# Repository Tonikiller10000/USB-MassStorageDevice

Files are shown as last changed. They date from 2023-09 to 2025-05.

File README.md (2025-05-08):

# USB MassStorageDevice

This project is an USB mass storage made with:
- 2x K9GAG08U0E 16GB NAND flash memory chips (32GB total) 
- lateral switch for read-only operation mode 
- an ST72681 memory controller 
- LD3985 3.3V regulator
- 12MHz crystal resonator
- other passive components

After testing the board with an 220nF THT ceramic capacitor because the SMD did not arrived in time, I made some improvisations trying to fix it, and
 it still `does not work`. It seems like the memory chip and the controller ic\`s are not compatible so 
 `I will have another look on this project in the distant future` with different components. I am looking into STM32 specs and usb 3.0 to SDMMC DMA transfer
 including some software functions with hardware interaction sounds verry intheresting. And cheaper.

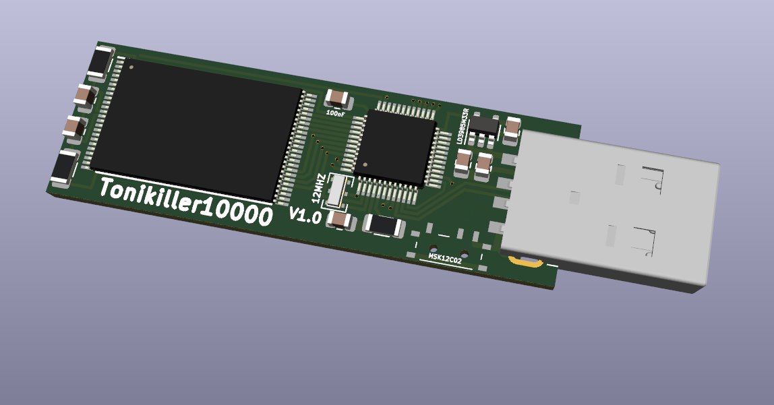
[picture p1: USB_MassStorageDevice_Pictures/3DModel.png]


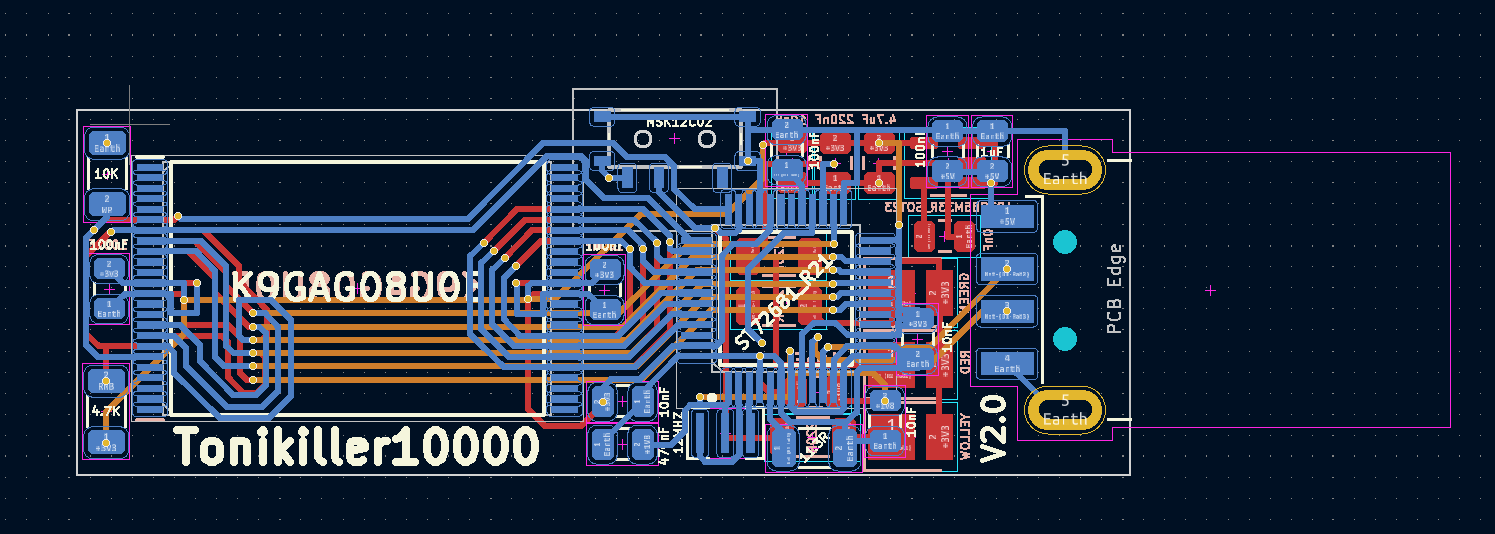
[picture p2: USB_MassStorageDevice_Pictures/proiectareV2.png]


Schematic:

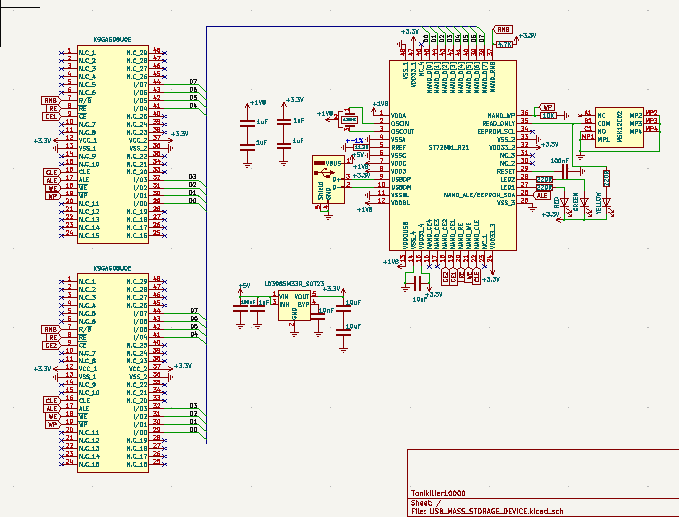
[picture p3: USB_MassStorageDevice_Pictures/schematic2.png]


<table>
  <tr>
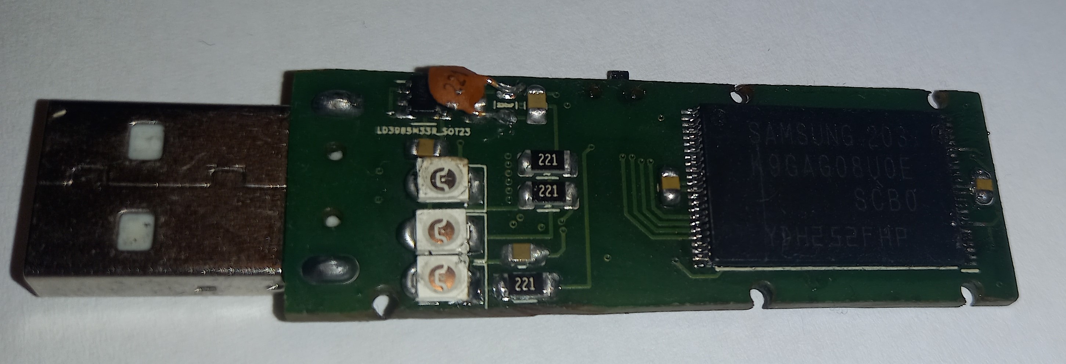
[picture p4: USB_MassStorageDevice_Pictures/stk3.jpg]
    <td></td>
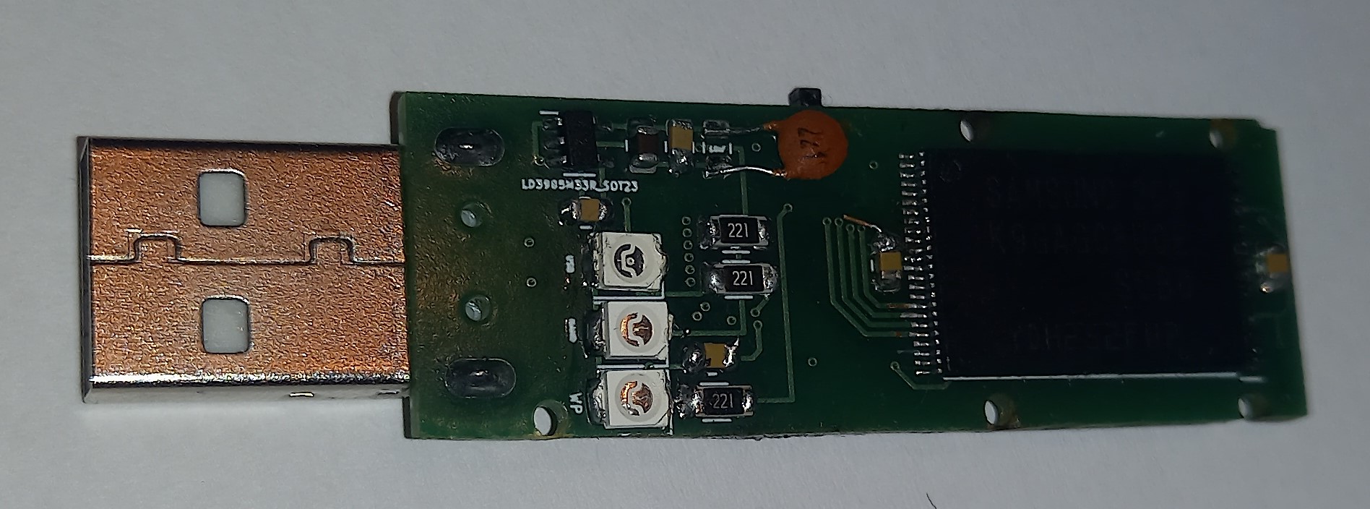
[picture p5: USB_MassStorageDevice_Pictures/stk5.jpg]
    <td></td>
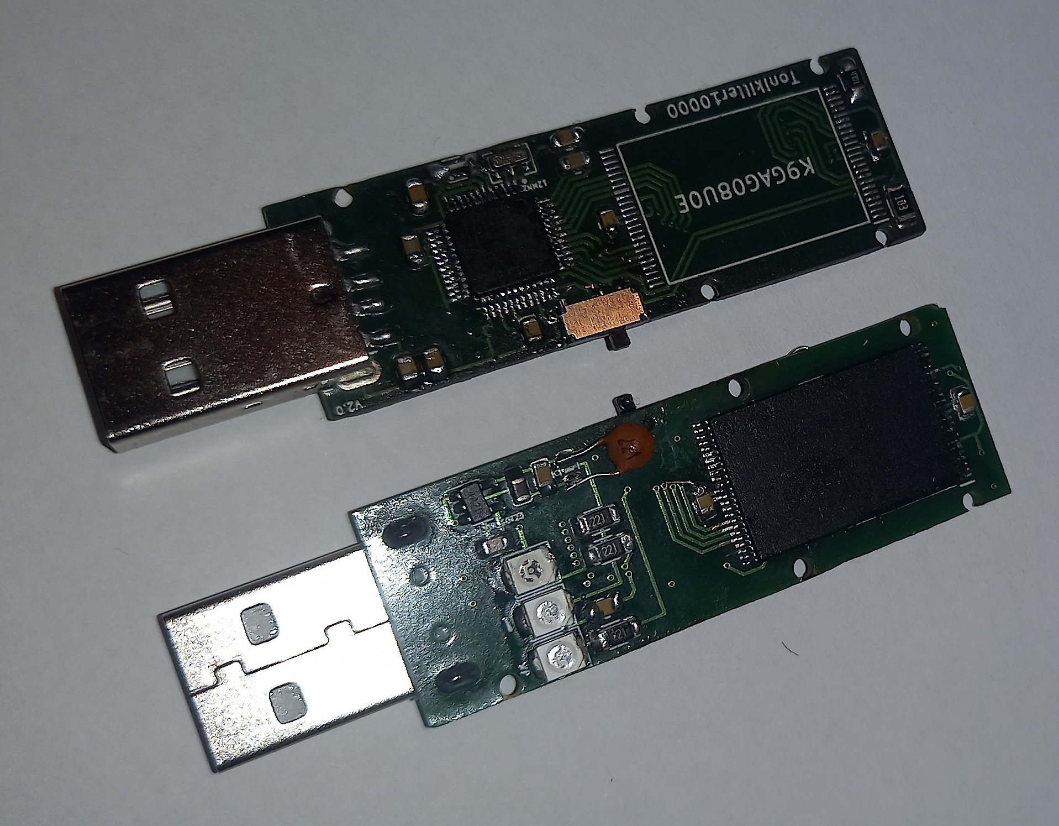
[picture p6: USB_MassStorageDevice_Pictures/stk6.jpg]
    <td></td>
  </tr>
 </table>

Datasheets:
- NAND: https://pdf1.alldatasheet.com/datasheet-pdf/view/104019/STMICROELECTRONICS/ST72681.html
- Controller: https://pdf1.alldatasheet.com/datasheet-pdf/view/1134995/SAMSUNG/K9GAG08U0E.html
- Regulator: https://pdf1.alldatasheet.com/datasheet-pdf/view/85490/STMICROELECTRONICS/LD3985.html

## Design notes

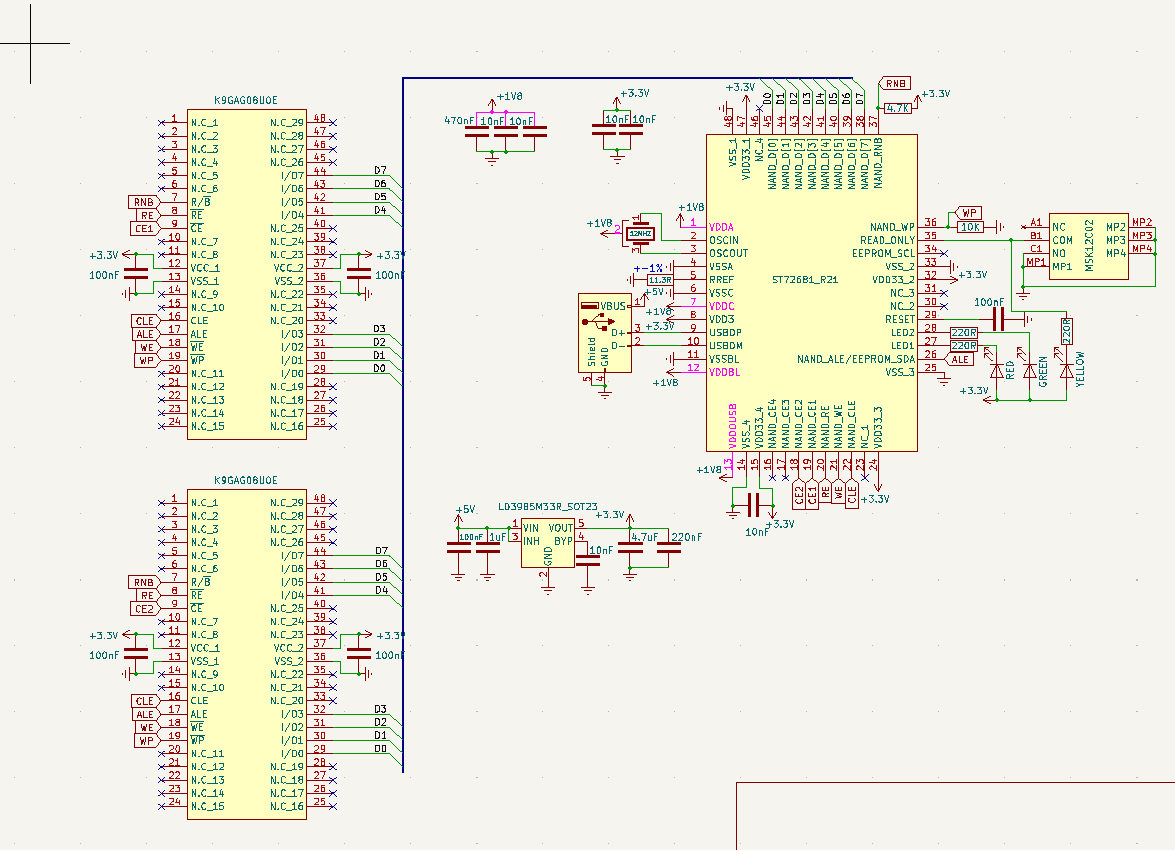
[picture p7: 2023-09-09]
USB_MassStorageDevice_Pictures/schematic.png

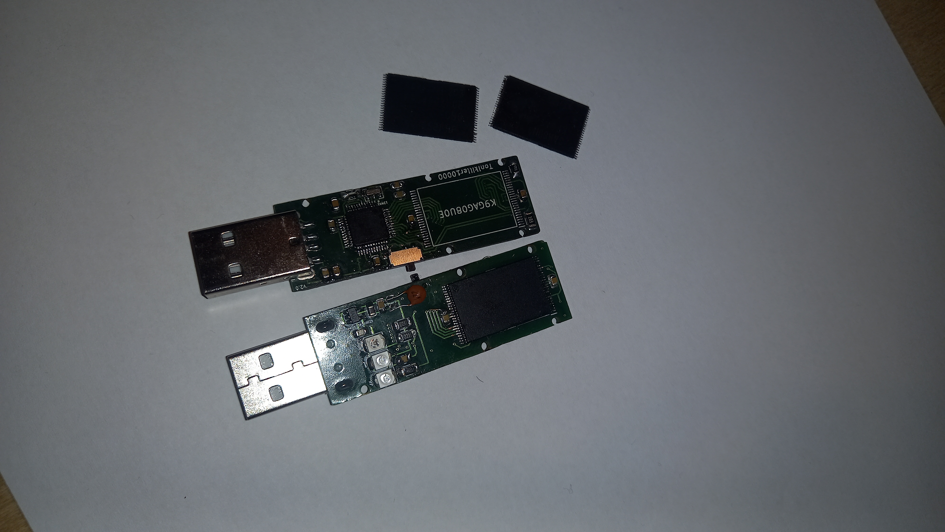
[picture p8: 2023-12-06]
USB_MassStorageDevice_Pictures/stk1.jpg

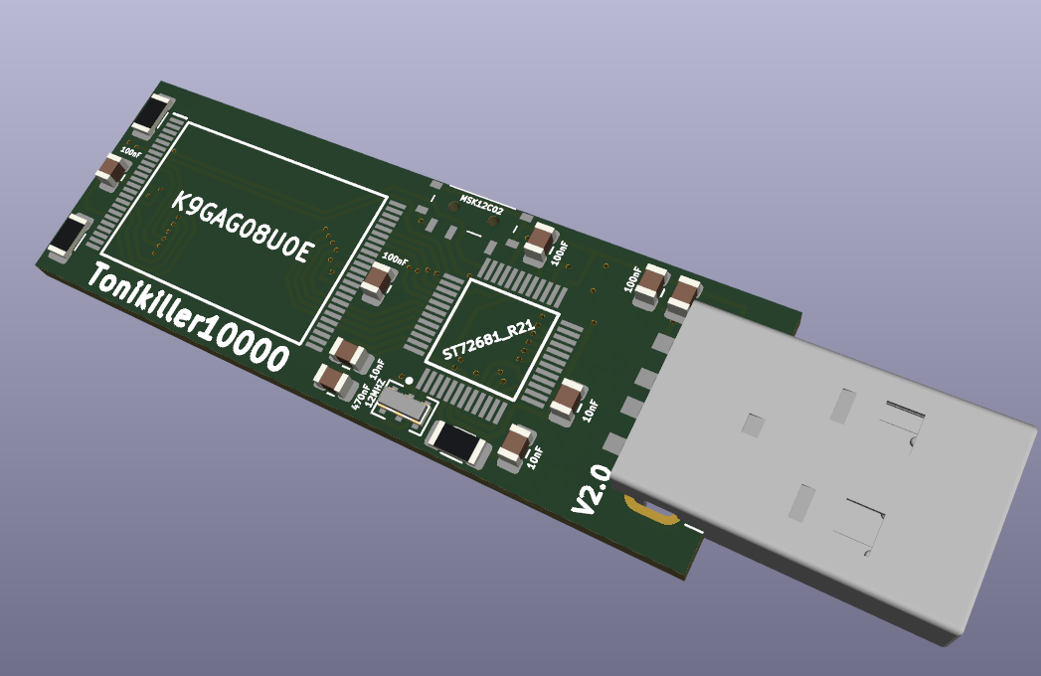
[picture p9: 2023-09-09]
USB_MassStorageDevice_Pictures/3DModel1.png

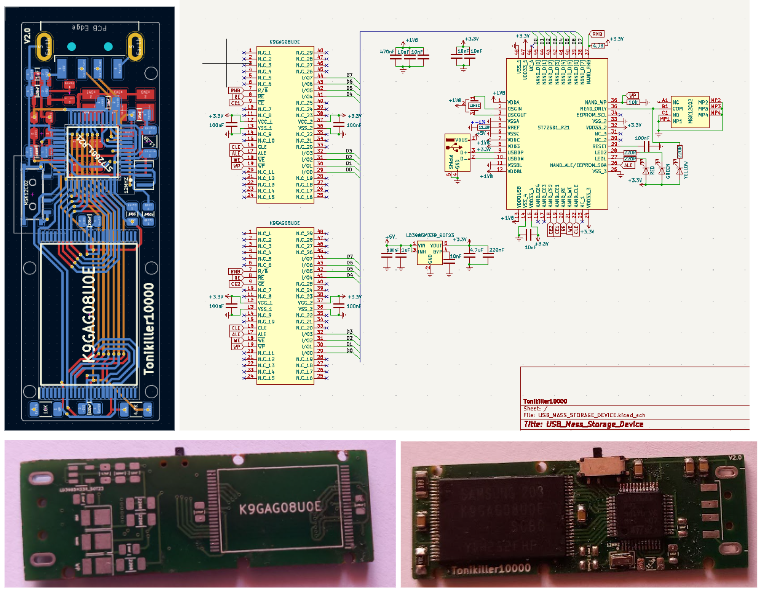
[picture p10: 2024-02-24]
USB_MassStorageDevice_Pictures/Screenshot 2023-11-07 201436.png

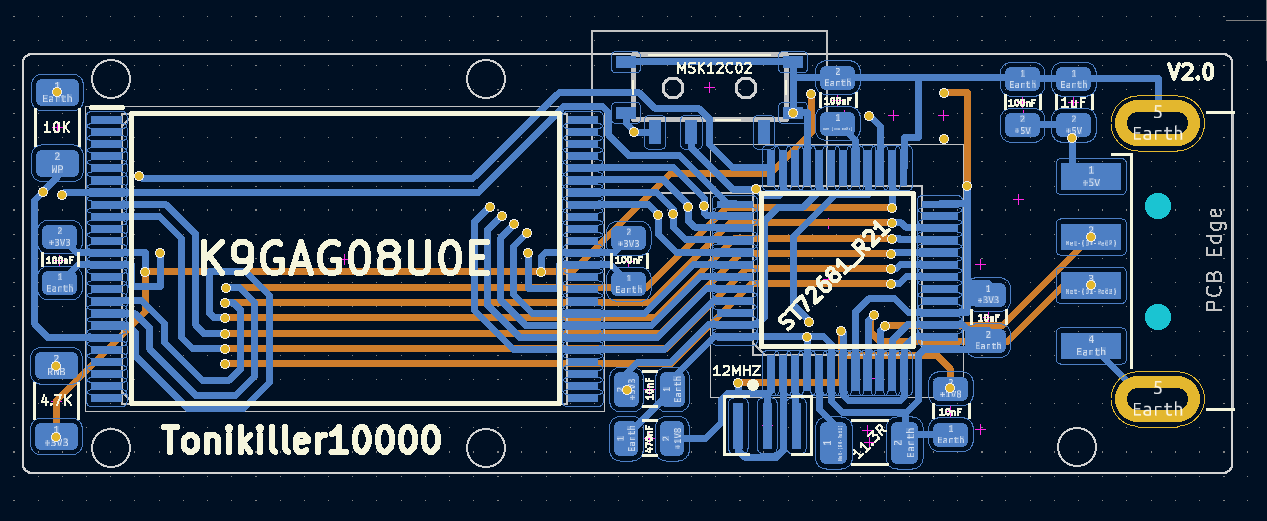
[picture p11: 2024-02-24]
USB_MassStorageDevice_Pictures/{EEEE6BA0-39D0-4342-B5F1-0E26C7068345}.png

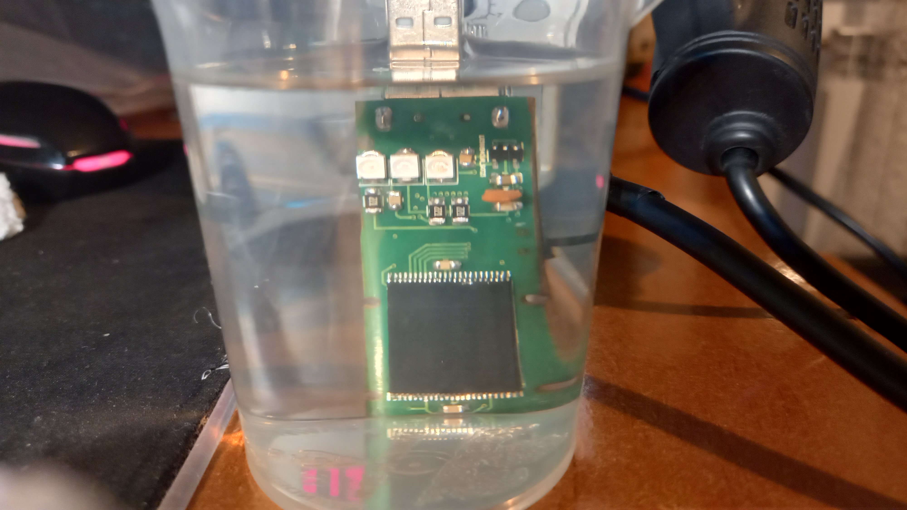
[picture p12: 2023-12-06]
USB_MassStorageDevice_Pictures/cleaning2.jpg

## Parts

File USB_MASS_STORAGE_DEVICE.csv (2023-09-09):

Source: | E:\toni\ARHIVA PC\Robotica\KICAD\USB_MASS_STORAGE_DEVICE\USB_MASS_STORAGE_DEVICE.kicad_sch
Date: | 25/08/2023 21:00:24
Tool: | Eeschema (6.0.5)
Generator: | E:\toni\Apps\6.0\bin\scripting\plugins/bom_csv_grouped_by_value.py
Component Count: | 32
Individual Components:
Item | Qty | Reference(s) | Value | LibPart | Footprint | Datasheet | Datasheet_1 | Footprint_1 | Height | Manufacturer_Name | Manufacturer_Part_Number | Mouser Part Number | Mouser Price/Stock | Reference_1 | Value_1
 |  | C1 | 100nF | Device:C | Capacitor_SMD:C_0805_2012Metric | ~
 |  | C2 | 100nF | Device:C | Capacitor_SMD:C_0805_2012Metric | ~
 |  | C3 | 100nF | Device:C | Capacitor_SMD:C_0805_2012Metric | ~
 |  | C4 | 10nF | Device:C | Capacitor_SMD:C_0805_2012Metric | ~
 |  | C5 | 100nF | Device:C | Capacitor_SMD:C_0805_2012Metric | ~
 |  | C6 | 100nF | Device:C | Capacitor_SMD:C_0805_2012Metric | ~
 |  | C7 | 470nF | Device:C | Capacitor_SMD:C_0805_2012Metric | ~
 |  | C8 | 1uF | Device:C | Capacitor_SMD:C_0805_2012Metric | ~
 |  | C10 | 10nF | Device:C | Capacitor_SMD:C_0805_2012Metric | ~
 |  | C11 | 10nF | Device:C | Capacitor_SMD:C_0805_2012Metric | ~
 |  | C12 | 4.7uF | Device:C | Capacitor_SMD:C_0805_2012Metric | ~
 |  | C13 | 10nF | Device:C | Capacitor_SMD:C_0805_2012Metric | ~
 |  | C14 | 100nF | Device:C | Capacitor_SMD:C_0805_2012Metric | ~
 |  | C16 | 10nF | Device:C | Capacitor_SMD:C_0805_2012Metric | ~
 |  | C17 | 10nF | Device:C | Capacitor_SMD:C_0805_2012Metric | ~
 |  | C19 | 220nF | Device:C | Capacitor_SMD:C_0805_2012Metric | ~
 |  | D1 | RED | Device:LED | LED_SMD:LED_PLCC_2835 | ~
 |  | D2 | GREEN | Device:LED | LED_SMD:LED_PLCC_2835 | ~
 |  | D3 | YELLOW | Device:LED | LED_SMD:LED_PLCC_2835 | ~
 |  | f1 | ST72681_R21 | ST72681:ST72681_R21 | ST72681_R21:QFP50P900X900X160-48N |  | https://www.st.com/resource/en/datasheet/cd00055081.pdf | QFP50P900X900X160-48N | 1.6 | STMicroelectronics | ST72681/R21 | N/A | https://www.mouser.com/Search/Refine.aspx?Keyword=N%2FA | IC | ST72681_R21
 |  | J1 | USB_A | Connector:USB_A | Connector_USB:USB_A_CNCTech_1001-011-01101_Horizontal | ~
 |  | m1 | K9GAG08U0E | K9GAG08U0E:K9GAG08U0E | K9GAG08U0E:SOP50P2000X120-48N |  | https://pdf1.alldatasheet.com/datasheet-pdf/view/1134995/SAMSUNG/K9GAG08U0E.html | SOP50P2000X120-48N | 1.2 | SAMSUNG | K9GAG08U0E |  |  | IC | K9GAG08U0E
 |  | m2 | K9GAG08U0E | K9GAG08U0E:K9GAG08U0E | K9GAG08U0E:SOP50P2000X120-48N |  | https://pdf1.alldatasheet.com/datasheet-pdf/view/1134995/SAMSUNG/K9GAG08U0E.html | SOP50P2000X120-48N | 1.2 | SAMSUNG | K9GAG08U0E |  |  | IC | K9GAG08U0E
 |  | R1 | 220R | Device:R | Resistor_SMD:R_1206_3216Metric | ~
 |  | R2 | 220R | Device:R | Resistor_SMD:R_1206_3216Metric | ~
 |  | R3 | 10K | Device:R | Resistor_SMD:R_1206_3216Metric | ~
 |  | R4 | 11.3R | Device:R | Resistor_SMD:R_1206_3216Metric | ~
 |  | R5 | 4.7K | Device:R | Resistor_SMD:R_1206_3216Metric | ~
 |  | R7 | 220R | Device:R | Resistor_SMD:R_1206_3216Metric | ~
 |  | SW1 | MSK12C02 | MSK12C02:MSK12C02 | MSK12C02:MSK12C02 |  | https://shouhan.en.made-in-china.com/product/xsMEmqgOAXWB/China-Slide-Switch-Msk12c02-Slide-Switch-on-off-2-Position-1p2t-Spdt-Miniature-Horizontal-SMD-7p-Sli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 | MSK12C02 | 1.4 | Shou Han | MSK12C02 |  |  | S | MSK12C02
 |  | U1 | LD3985M33R_SOT23 | Regulator_Linear:LD3985M33R_SOT23 | Package_TO_SOT_SMD:SOT-23-5 | http://www.st.com/internet/com/TECHNICAL_RESOURCES/TECHNICAL_LITERATURE/DATASHEET/CD00003395.pdf
 |  | Y2 | 12MHZ | Device:Crystal_GND3 | Crystal:Resonator_SMD_Murata_CSTxExxV-3Pin_3.0x1.1mm | ~
Collated Components:
Item | Qty | Reference(s) | Value | LibPart | Footprint | Datasheet | Datasheet_1 | Footprint_1 | Height | Manufacturer_Name | Manufacturer_Part_Number | Mouser Part Number | Mouser Price/Stock | Reference_1 | Value_1
1 | 6 | C1, C2, C3, C5, C6, C14 | 100nF | Device:C | Capacitor_SMD:C_0805_2012Metric | ~
2 | 6 | C4, C10, C11, C13, C16, C17 | 10nF | Device:C | Capacitor_SMD:C_0805_2012Metric | ~
3 | 1 | C7 | 470nF | Device:C | Capacitor_SMD:C_0805_2012Metric | ~
4 | 1 | C8 | 1uF | Device:C | Capacitor_SMD:C_0805_2012Metric | ~
5 | 1 | C12 | 4.7uF | Device:C | Capacitor_SMD:C_0805_2012Metric | ~
6 | 1 | C19 | 220nF | Device:C | Capacitor_SMD:C_0805_2012Metric | ~
7 | 1 | D1 | RED | Device:LED | LED_SMD:LED_PLCC_2835 | ~
8 | 1 | D2 | GREEN | Device:LED | LED_SMD:LED_PLCC_2835 | ~
9 | 1 | D3 | YELLOW | Device:LED | LED_SMD:LED_PLCC_2835 | ~
10 | 1 | f1 | ST72681_R21 | ST72681:ST72681_R21 | ST72681_R21:QFP50P900X900X160-48N |  | https://www.st.com/resource/en/datasheet/cd00055081.pdf | QFP50P900X900X160-48N | 1.6 | STMicroelectronics | ST72681/R21 | N/A | https://www.mouser.com/Search/Refine.aspx?Keyword=N%2FA | IC | ST72681_R21
11 | 1 | J1 | USB_A | Connector:USB_A | Connector_USB:USB_A_CNCTech_1001-011-01101_Horizontal | ~
12 | 2 | m1, m2 | K9GAG08U0E | K9GAG08U0E:K9GAG08U0E | K9GAG08U0E:SOP50P2000X120-48N |  | https://pdf1.alldatasheet.com/datasheet-pdf/view/1134995/SAMSUNG/K9GAG08U0E.html | SOP50P2000X120-48N | 1.2 | SAMSUNG | K9GAG08U0E |  |  | IC | K9GAG08U0E
13 | 3 | R1, R2, R7 | 220R | Device:R | Resistor_SMD:R_1206_3216Metric | ~
14 | 1 | R3 | 10K | Device:R | Resistor_SMD:R_1206_3216Metric | ~
15 | 1 | R4 | 11.3R | Device:R | Resistor_SMD:R_1206_3216Metric | ~
16 | 1 | R5 | 4.7K | Device:R | Resistor_SMD:R_1206_3216Metric | ~
17 | 1 | SW1 | MSK12C02 | MSK12C02:MSK12C02 | MSK12C02:MSK12C02 |  | https://shouhan.en.made-in-china.com/product/xsMEmqgOAXWB/China-Slide-Switch-Msk12c02-Slide-Switch-on-off-2-Position-1p2t-Spdt-Miniature-Horizontal-SMD-7p-Sli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 | MSK12C02 | 1.4 | Shou Han | MSK12C02 |  |  | S | MSK12C02
18 | 1 | U1 | LD3985M33R_SOT23 | Regulator_Linear:LD3985M33R_SOT23 | Package_TO_SOT_SMD:SOT-23-5 | http://www.st.com/internet/com/TECHNICAL_RESOURCES/TECHNICAL_LITERATURE/DATASHEET/CD00003395.pdf
19 | 1 | Y2 | 12MHZ | Device:Crystal_GND3 | Crystal:Resonator_SMD_Murata_CSTxExxV-3Pin_3.0x1.1mm | ~

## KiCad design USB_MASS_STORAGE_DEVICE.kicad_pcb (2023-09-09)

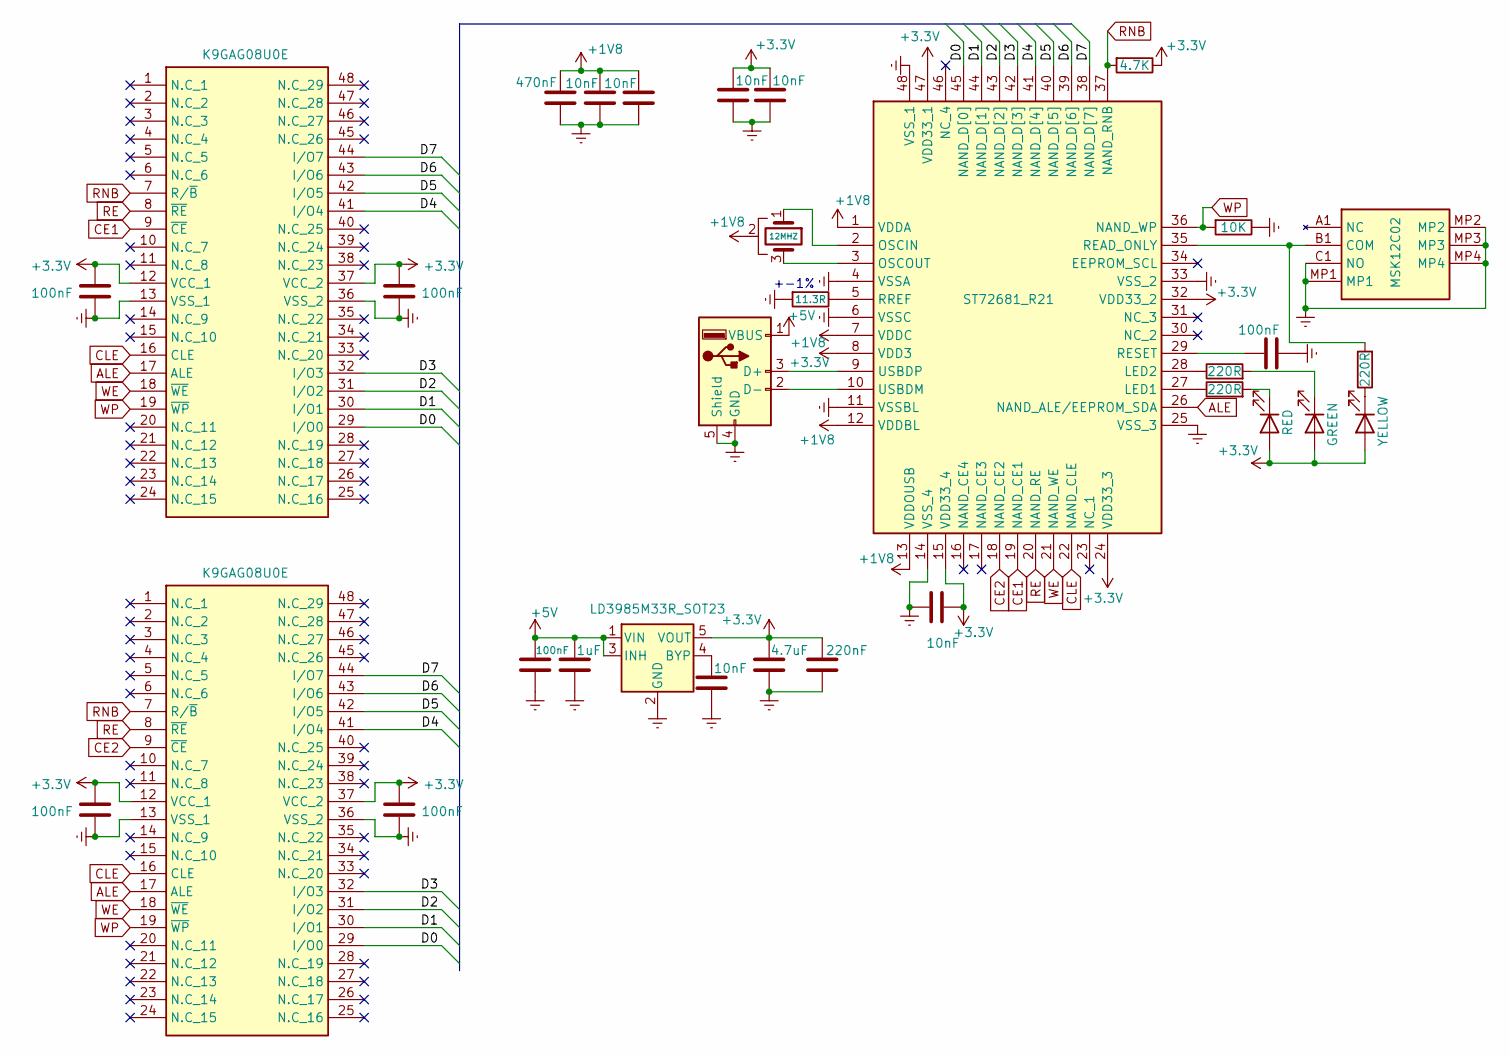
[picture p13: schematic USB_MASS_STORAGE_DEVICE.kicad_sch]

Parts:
C1, C2, C3, C5, C6, C14: 100nF; C_0805_2012Metric
C4, C10, C11, C13, C16, C17: 10nF; C_0805_2012Metric
C7: 470nF; C_0805_2012Metric
C8: 1uF; C_0805_2012Metric
C12: 4.7uF; C_0805_2012Metric
C19: 220nF; C_0805_2012Metric
D1: RED; LED_PLCC_2835
D2: GREEN; LED_PLCC_2835
D3: YELLOW; LED_PLCC_2835
J1: USB_A; USB_A_CNCTech_1001-011-01101_Horizontal
R1, R2, R7: 220R; R_1206_3216Metric
R3: 10K; R_1206_3216Metric
R4: 11.3R; R_1206_3216Metric
R5: 4.7K; R_1206_3216Metric
SW1: MSK12C02; Manufacturer_Part_Number MSK12C02
U1: LD3985M33R_SOT23; SOT-23-5
Y2: 12MHZ; Resonator_SMD_Murata_CSTxExxV-3Pin_3.0x1.1mm
f1: ST72681_R21; QFP50P900X900X160-48N; Manufacturer_Part_Number ST72681/R21; Mouser Part Number N/A
m1, m2: K9GAG08U0E; SOP50P2000X120-48N; Manufacturer_Part_Number K9GAG08U0E

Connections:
+1V8: C7.2, C10.2, C13.2, Y2.2, f1.1 (VDDA), f1.7 (VDDC), f1.12 (VDDBL), f1.13 (VDDOUSB)
+3V3: C1.2, C2.2, C3.2, C4.1, C6.2, C12.2, C16.2, C17.2, C19.2, D1.2 (A), D2.2 (A), D3.2 (A), R5.1, U1.5 (VOUT), f1.8 (VDD3), f1.15 (VDD33_4), f1.24 (VDD33_3), f1.32 (VDD33_2), f1.47 (VDD33_1), m1.12 (VCC_1), m1.37 (VCC_2), m2.12 (VCC_1), m2.37 (VCC_2)
+5V: C5.2, C8.2, J1.1 (VBUS), U1.1 (VIN), U1.3 (INH)
/D0: f1.45 (NAND_D[0]), m1.29 (I/O0), m2.29 (I/O0)
/D1: f1.44 (NAND_D[1]), m1.30 (I/O1), m2.30 (I/O1)
/D2: f1.43 (NAND_D[2]), m1.31 (I/O2), m2.31 (I/O2)
/D3: f1.42 (NAND_D[3]), m1.32 (I/O3), m2.32 (I/O3)
/D4: f1.41 (NAND_D[4]), m1.41 (I/O4), m2.41 (I/O4)
/D5: f1.40 (NAND_D[5]), m1.42 (I/O5), m2.42 (I/O5)
/D6: f1.39 (NAND_D[6]), m1.43 (I/O6), m2.43 (I/O6)
/D7: f1.38 (NAND_D[7]), m1.44 (I/O7), m2.44 (I/O7)
ALE: f1.26 (NAND_ALE/EEPROM_SDA), m1.17 (ALE), m2.17 (ALE)
CE1: f1.19 (NAND_CE1), m1.9 (~CE)
CE2: f1.18 (NAND_CE2), m2.9 (~CE)
CLE: f1.22 (NAND_CLE), m1.16 (CLE), m2.16 (CLE)
Earth: C1.1, C2.1, C3.1, C4.2, C5.1, C6.1, C7.1, C8.1, C10.1, C11.1, C12.1, C13.1, C14.2, C16.1, C17.1, C19.1, J1.4 (GND), J1.5 (Shield), R3.1, R4.2, SW1.C1 (NO), SW1.MP1, SW1.MP2, SW1.MP3, SW1.MP4, U1.2 (GND), f1.4 (VSSA), f1.6 (VSSC), f1.11 (VSSBL), f1.14 (VSS_4), f1.25 (VSS_3), f1.33 (VSS_2), f1.48 (VSS_1), m1.13 (VSS_1), m1.36 (VSS_2), m2.13 (VSS_1), m2.36 (VSS_2)
unnamed: C11.2, U1.4 (BYP)
unnamed: C14.1, f1.29 (RESET)
unnamed: J1.2 (D-), f1.10 (USBDM)
unnamed: J1.3 (D+), f1.9 (USBDP)
unnamed: R1.1, f1.28 (LED2)
unnamed: D2.1 (K), R1.2
unnamed: R2.1, f1.27 (LED1)
unnamed: D1.1 (K), R2.2
unnamed: R4.1, f1.5 (RREF)
unnamed: D3.1 (K), R7.1
unnamed: R7.2, SW1.B1 (COM), f1.35 (READ_ONLY)
unnamed: Y2.1, f1.2 (OSCIN)
unnamed: Y2.3, f1.3 (OSCOUT)
RE: f1.20 (NAND_RE), m1.8 (~RE), m2.8 (~RE)
RNB: R5.2, f1.37 (NAND_RNB), m1.7 (R/~B), m2.7 (R/~B)
WE: f1.21 (NAND_WE), m1.18 (~WE), m2.18 (~WE)
WP: R3.2, f1.36 (NAND_WP), m1.19 (~WP), m2.19 (~WP)

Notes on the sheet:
+-1%

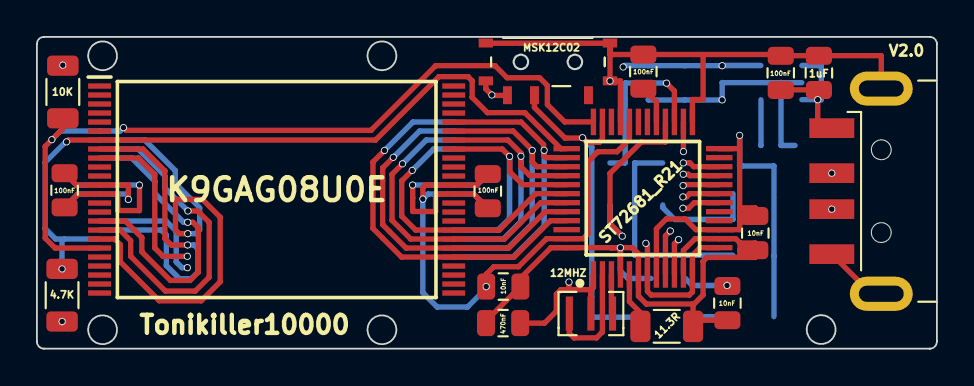
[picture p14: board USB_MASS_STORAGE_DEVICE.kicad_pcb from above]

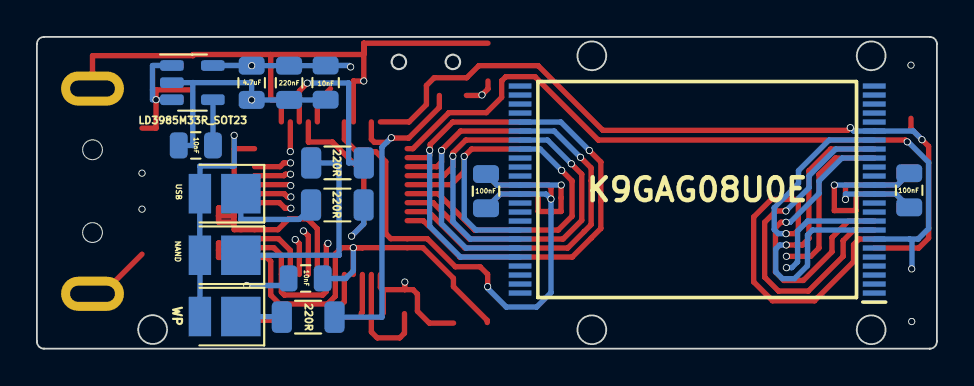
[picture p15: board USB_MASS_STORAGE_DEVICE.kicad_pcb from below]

Board: 4 copper layers, 50.0 x 17.3 mm, 32 parts (15 on the bottom side), 33 nets.
